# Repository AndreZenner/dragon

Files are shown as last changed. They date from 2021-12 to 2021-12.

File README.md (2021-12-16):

# Drag:on

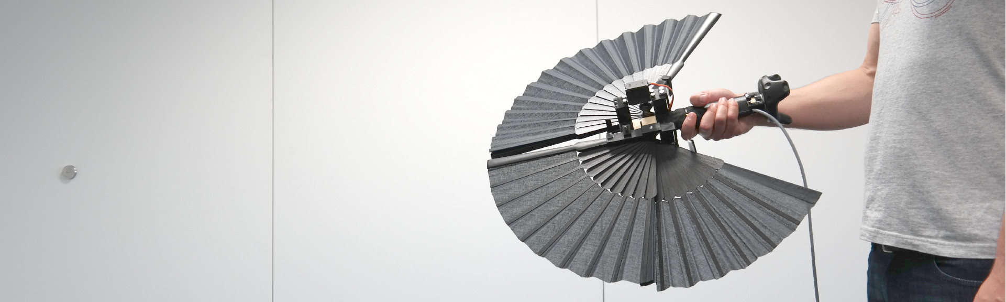
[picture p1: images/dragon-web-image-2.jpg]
Picture of the Drag:on The Drag:on


An assembly kit to build a **Drag:on virtual reality controller with haptic feedback based on air resistance**.  
Below you will find useful links and general instructions, as well as the necessary files, code, and documents.  

Please refer to this repository if you want to re-build Drag:on for private use.
Commercial use of Drag:on and its underlying feedback concept is protected by the following [patent](https://register.dpma.de/DPMAregister/pat/PatSchrifteneinsicht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):

```
Zenner, A. and Krüger, A. (2021). Hand-Virtual Reality/Augmented Reality-Steuergerät, VirtualReality/Augmented Reality-System mit demselben sowie Verfahren zur Simulation der Haptik.
German Patent 10 2019 105 854. June 05, 2021.
Link: https://register.dpma.de/DPMAregister/pat/PatSchrifteneinsicht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
```

## Paper & Video
The original prototype by [André Zenner (DFKI, Germany)](https://umtl.cs.uni-saarland.de/people/andre-zenner.html) and [Antonio Krüger (DFKI, Germany)](https://umtl.cs.uni-saarland.de/people/prof.-dr.-antonio-kr%C3%BCger.html) is described in detail in the corresponding research article.  
Here you can find the [paper](https://umtl.cs.uni-saarland.de/paper_preprints/zenner-krueger-dragon-chi-19-pre-print.pdf) and [video](https://youtu.be/Wf1Ls4M2afg).

### Reference
Please cite the research article using the reference information below:
```
André Zenner and Antonio Krüger. 2019. 
Drag:on - A Virtual Reality Controller Providing Haptic Feedback Based on Drag and Weight Shift. 
In Proceedings of the 2019 CHI Conference on Human Factors in Computing Systems (CHI ’19). 
Association for Computing Machinery, New York, NY, USA, Paper 211, 1–12. 
DOI: https://doi.org/10.1145/3290605.3300441
```

### BibTeX
If using BibTeX, please use the entry below:
```
@inproceedings{Zenner:2019:Dragon,
author = {Zenner, Andr\'{e} and Kr\"{u}ger, Antonio},
title = {Drag:on -- A Virtual Reality Controller Providing Haptic Feedback Based on Drag and Weight Shift},
year = {2019},
isbn = {9781450359702},
publisher = {Association for Computing Machinery},
address = {New York, NY, USA},
url = {https://doi.org/10.1145/3290605.3300441},
doi = {10.1145/3290605.3300441},
booktitle = {Proceedings of the 2019 CHI Conference on Human Factors in Computing Systems},
pages = {1–12},
numpages = {12},
keywords = {haptic virtual reality controller, shape-changing devices, air resistance feedback, dynamic passive haptic feedback},
location = {Glasgow, Scotland Uk},
series = {CHI ’19}
}
```

## What You Will Need
Apart from the ability to solder basic components and basic DIY skills, you will need access to:
*  soldering equipment
*  a workbench
*  a 3D printer
*  a laser cutter (optional)

## Required Parts
To build a Drag:on, you will need the basic physical parts listed below:

| Amount | Part | Comment |
| --- | --- | --- |
| 1 | 7.5V Power Supply | [Example](https://www.amazon.de/s?k=Universal+Netzteil&__mk_de_DE=%C3%85M%C3%85%C5%BD%C3%95%C3%91&ref=nb_sb_noss_2) |
| > 10m | Cable (8 poles, shielded) | [Example](https://www.reichelt.de/steuerleitung-8x0-14mm-geschirmt-50m-ring-liycy-08-50-p10314.html?&trstct=pos_0&nbc=1) |
| 1 | Plug (8 poles) | must match socket |
| 1 | Socket (8 poles) | [Example](https://www.reichelt.de/mikrofon-kupplung-f-funkgeraete-8-polig-m-608-p11166.html?&trstct=pos_0&nbc=1) |
| 2 | MG996R servo motor with metal gears | [Example](https://www.amazon.de/dp/B07H89JH74/ref=pe_3044161_185740101_TE_item) |
| 1 | Power supply socket | [Example](https://www.ebay.de/itm/5x-Stromversorgungsbuchse-fur-Arduino-5-5-2-1mm-DC022B-Hohlstecker-Einbau/182920397905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) |
| 1 | 1/4 inch screw (camera screw; 12mm x 14mm) | [Example](https://www.amazon.de/dp/B0725VQ2N3/ref=pe_3044161_185740101_TE_item) |
| 1 pack | tesa Powerstrips Large | [Example](https://www.amazon.de/dp/B000KJOC78/ref=pe_3044161_185740101_TE_item) |
| 1 | Arduino Nano | [Example](https://store.arduino.cc/arduino-nano) |
| 1 | Button | [Example](https://www.amazon.de/dp/B07DF5NTZN/ref=pe_3044161_185740101_TE_item) |
| 1 | Vive Tracker | [Example](https://www.vive.com/de/vive-tracker/) |
| 2 | Fans (31 cm) | [Example](https://www.flamenco-kleider.de/product_info.php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) |
| | 3D printed parts | see [3d-printer](3d-printer) |
| 1 | Drag:on PCB (or Breadboard) | see [circuit](circuit) |
| | basic electronic parts (resistors, capacitors, etc.) | see [circuit](circuit) |
| (1) | box to hold the electronics | see [laser-cutter](laser-cutter) |

## Required Files
Apart from the physical parts, you will need a set of files.  
All these files can be found in this Git repository:
*  3D models (`*.stl` format) to print in folder [`3d-printer`](3d-printer)
*  laser cutter templates (`*.svg` format) to cut in folder [`laser-cutter`](laser-cutter)
*  circuit description (an image) in folder [`circuit`](circuit)
*  source code for the Arduino Nano (the Drag:on firmware) in folder [`dragon-arduino`](dragon-arduino)
*  source code for Unity (the Drag:on `.unitypackage`) in folder [`dragon-unity`](dragon-unity)

## Main Steps
Follow the steps below to build a Drag:on.

### Preparation
1.  Buy all necessary components (see table above)
2.  3D print all required parts (see [video](https://youtu.be/Wf1Ls4M2afg) for part count and [`3d-printer`](3d-printer) for files)
3.  (Laser cut a nice box to hold the electronics - optional - see [`laser-cutter`](laser-cutter) for files and image below for an example)

### Assembly
1.  Assemble the circuit (see image below and [`circuit`](circuit))
2.  Assemble the actual device using the parts you bought and the 3D-printed components. Refer to the [video](https://youtu.be/Wf1Ls4M2afg) and the images on this site to see how it should look at the end. Also, take a look at the [explosion animation](https://youtu.be/Wf1Ls4M2afg?t=117). If you need close-up pictures of any details or parts, please contact [André Zenner](https://umtl.cs.uni-saarland.de/people/andre-zenner.html) (andre.zenner@dfki.de).
3.  Deploy the Arduino source code on the Nano (see [`dragon-arduino`](dragon-arduino))

Drag:on Rendering 1 | Drag:on Rendering 2 | Drag:on Rendering 3
:-------------------------:|:-------------------------:|:-------------------------:
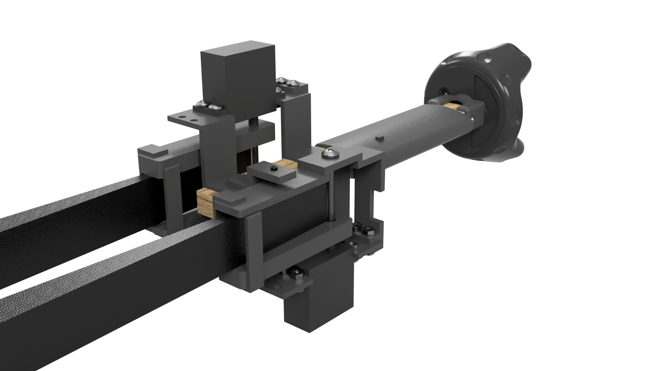
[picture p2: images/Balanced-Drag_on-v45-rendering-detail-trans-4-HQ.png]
Drag:on Rendering 1
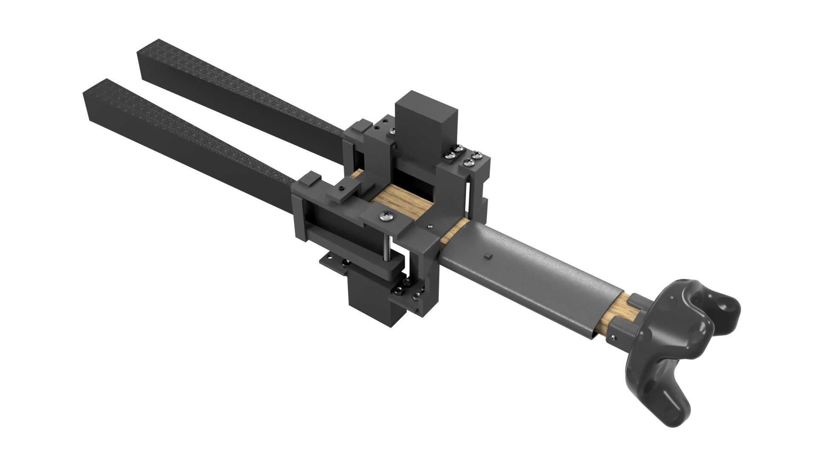
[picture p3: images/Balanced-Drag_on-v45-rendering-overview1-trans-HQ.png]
Drag:on Rendering 2
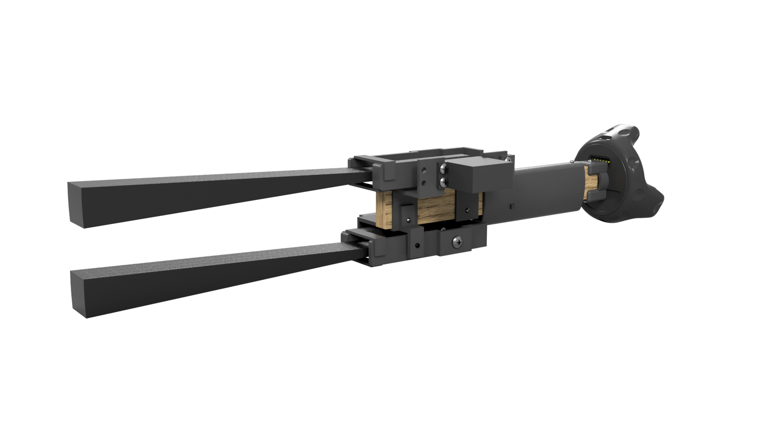
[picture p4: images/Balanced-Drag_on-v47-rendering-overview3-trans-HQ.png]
Drag:on Rendering 3
  |   | 

Drag:on Controller Box | Drag:on Circuit | Final Drag:on
:-------------------------:|:-------------------------:|:-------------------------:
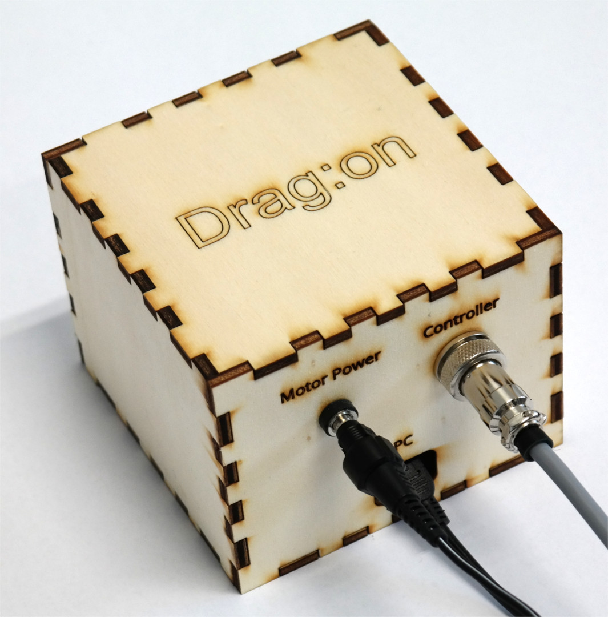
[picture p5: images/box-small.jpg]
Picture of the Drag:on box The Drag:on box.
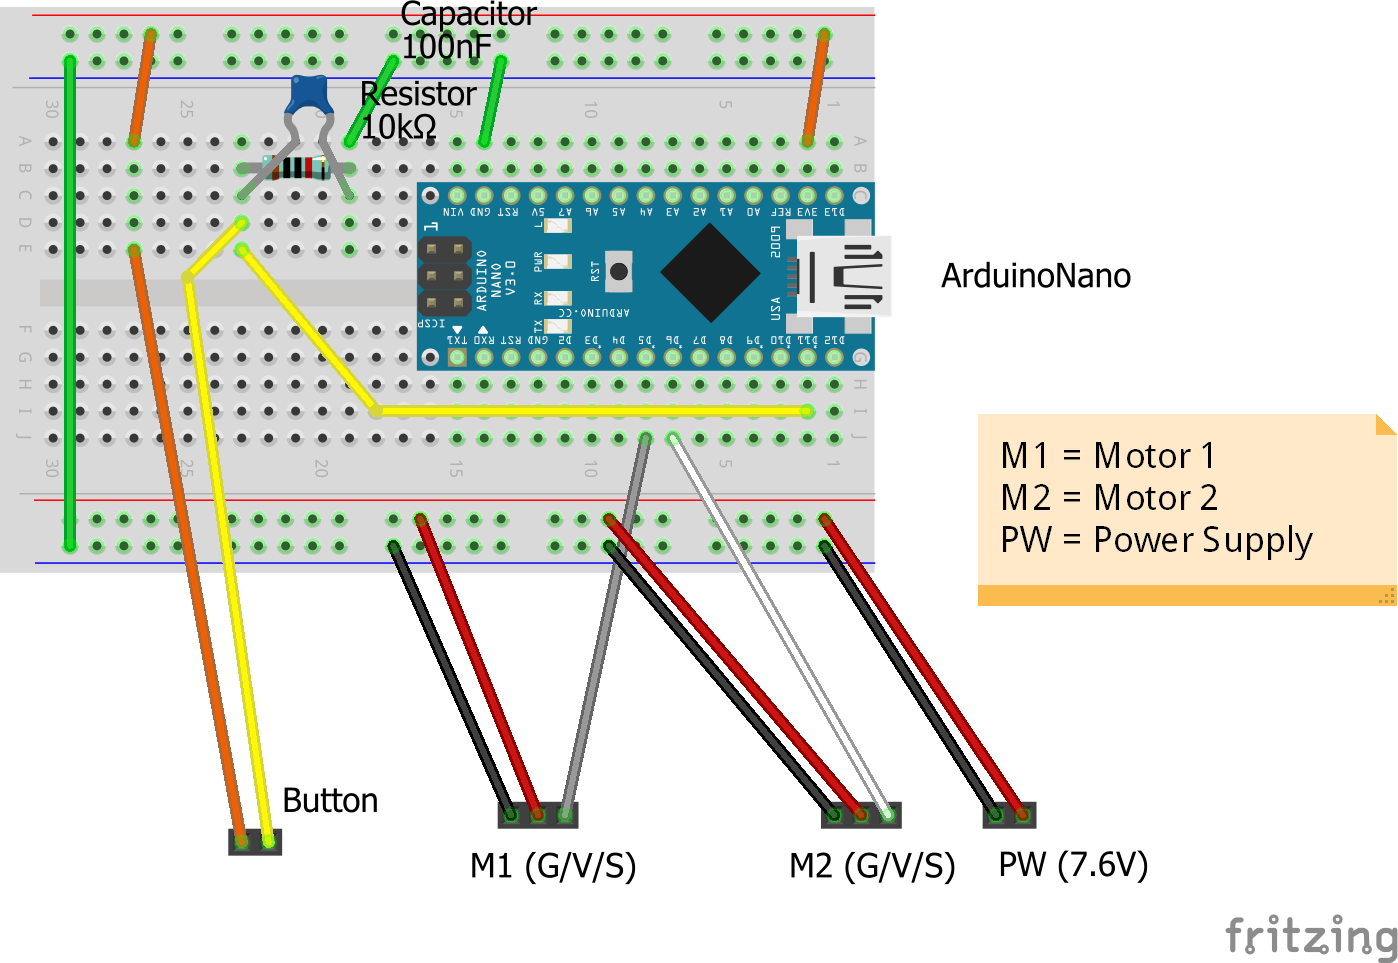
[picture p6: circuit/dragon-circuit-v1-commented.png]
Illustration of the Drag:on circuit The Drag:on circuit.
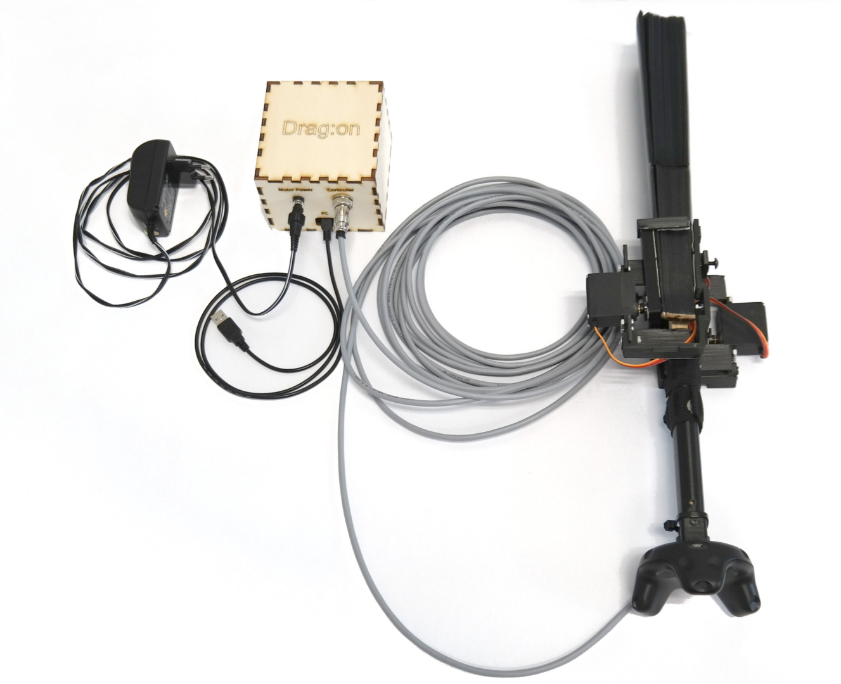
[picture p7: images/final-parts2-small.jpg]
Picture of the final assembly The assembled parts of the Drag:on.
 |   | 

### Standalone Test
1.  Connect everything
2.  Test the device itself (standalone mode). For this, start the device by powering it up while holding the button pressed. Now each button press should change the state of the Drag:on and move its two fans.

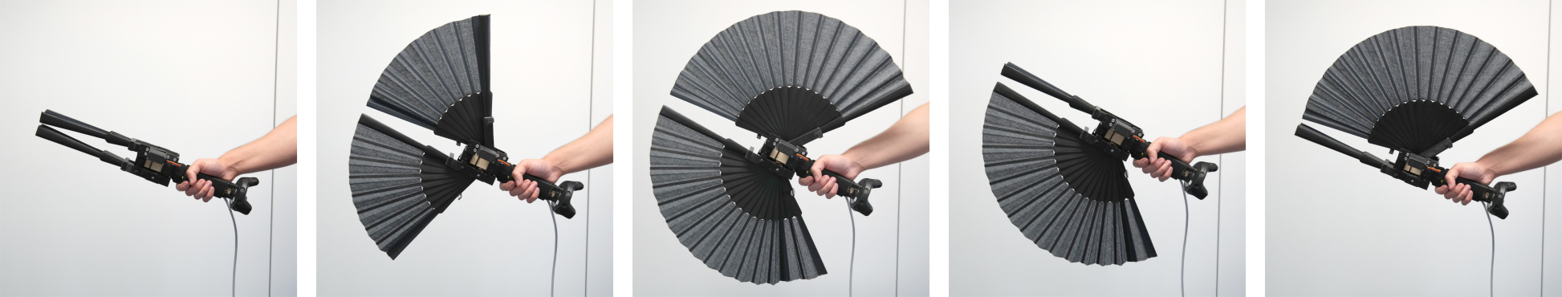
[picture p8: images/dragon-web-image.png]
Picture of the Drag:on states The Drag:on states.


### Unity Integration
1.  If the standalone test was successful, turn to the Unity Package provided in [`dragon-unity`](dragon-unity).
    1.  Import the package into a new Unity project.
    2.  To use the COM port connection to the Drag:on device, you have to switch to `.NET 4.x` support. For this, go to `Edit -> Project Settings -> Player` and select as `Api Compatibility Level` `.NET 4.x` (instead of `.NET Standard 2.0`; see screenshots below).
    3.  When the initial errors are fixed, have a look at the example scene that integrates the device.
        1.  The scene contains a prefab `Drag:on` that holds a simple 3D model of the device, text indicators to display the current device transformation progress, and most importantly, the `Dragon.cs` and `DragonTest.cs` C# scripts.
        2.  The `Dragon` script implements the interface to send commands to the Drag:on device and read out its internal state. Be sure to **select the correct COM port in the Unity Editor** (see left image below).
        3.  The `DragonTest` script allows to easily trigger the important functions for test purposes via the keyboard. Just hover over "Dragon" to see a tooltip. You can select the desired target fan positions using the sliders `Percent A` and `Percent B` and then press `2` on the keyboard to transform Drag:on into this state (see right image below).
        4.  Please see the comments in the code for additional information.
2.  To integrate the device into a VR application, use a Vive Tracker and the [SteamVR Plugin](https://assetstore.unity.com/packages/tools/integration/steamvr-plugin-32647).
    1.  Screw the Vive Tracker to the Tracker Module at the end of the device grip.
    2.  Calibrate the tracking in the scene so that the real and virtual Drag:on are aligned.

Initial Errors | Select `Project Settings` | Switch `API Compaltibility Level`
:-------------------------:|:-------------------------:|:-------------------------:
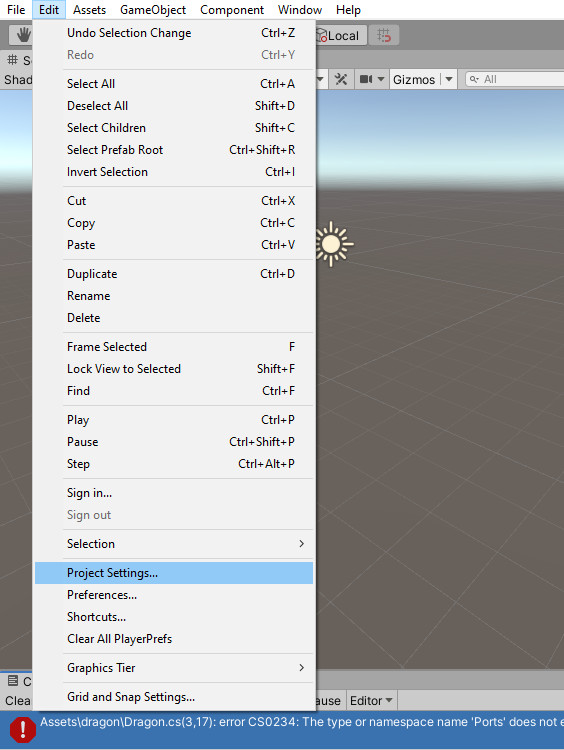
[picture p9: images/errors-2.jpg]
Select Project Settings Select Project Settings.
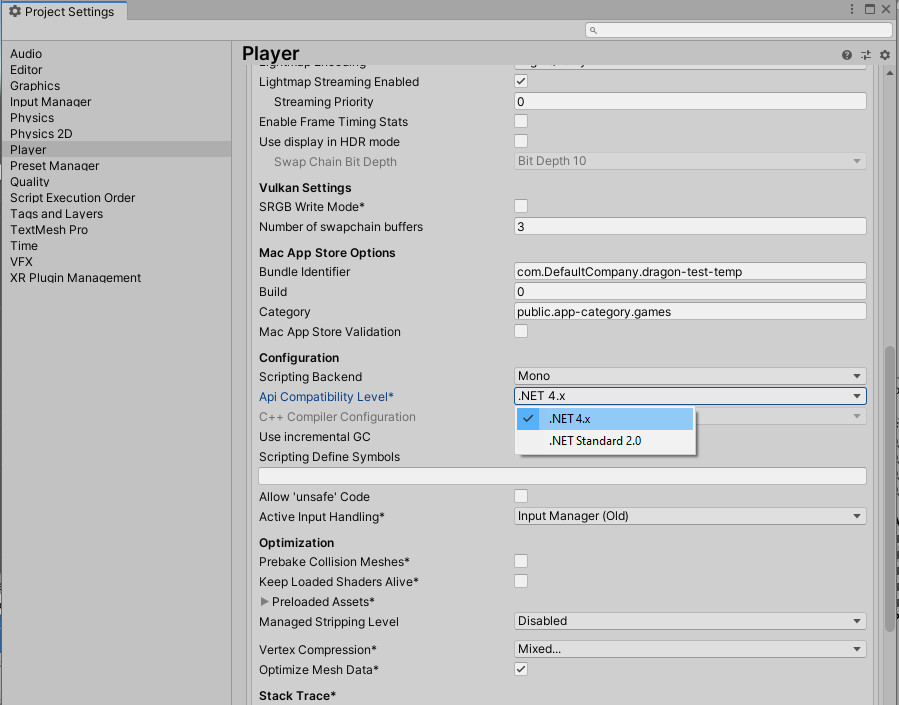
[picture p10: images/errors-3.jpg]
Switch API Compaltibility Level Switch API Compaltibility Level.
The expected initial errors The expected initial errors. |   | 

`Dragon.cs` script | `DragonTest.cs` script
:-------------------------:|:-------------------------:
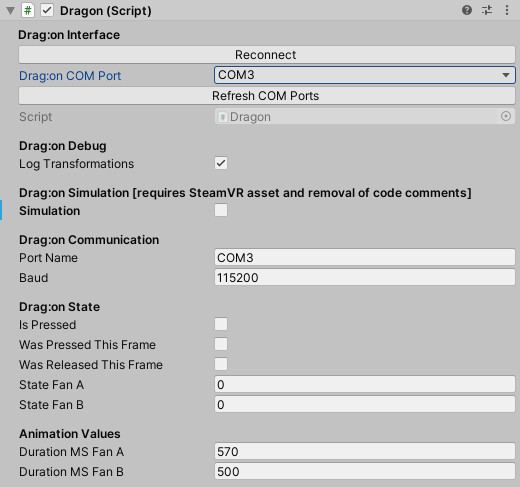
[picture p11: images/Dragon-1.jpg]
Screenshot of the Dragon.cs script Unity Editor interface The Dragon.cs script Unity Editor interface.
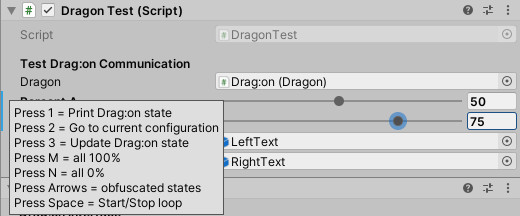
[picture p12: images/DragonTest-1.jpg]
Screenshot of the DragonTest.cs script Unity Editor interface The DragonTest.cs script Unity Editor interface.
 | 

## Contact
For any questions contact [André Zenner](https://umtl.cs.uni-saarland.de/people/andre-zenner.html) (andre.zenner@dfki.de).

## Attribution
When you use a Drag:on in your project, please acknowledge the original [paper](https://umtl.cs.uni-saarland.de/paper_preprints/zenner-krueger-dragon-chi-19-pre-print.pdf) and the resources provided by the authors to build the device in your official documents, published papers, videos, or websites (by citing the paper using the reference above and acknowledging the support).  
**Please also inform [André Zenner](https://umtl.cs.uni-saarland.de/people/andre-zenner.html) (andre.zenner@dfki.de) about your project - we love to hear about it and see what you'll use the Drag:on for!**

This work was supported by the [Deutsches Forschungszentrum für Künstliche Intelligenz GmbH](https://www.dfki.de/) (DFKI; German Research Center for Artificial Intelligence) and [Saarland University](https://www.uni-saarland.de/).
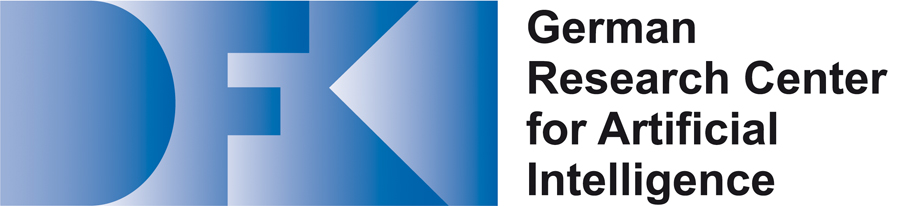
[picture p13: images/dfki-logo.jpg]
DFKI Logo

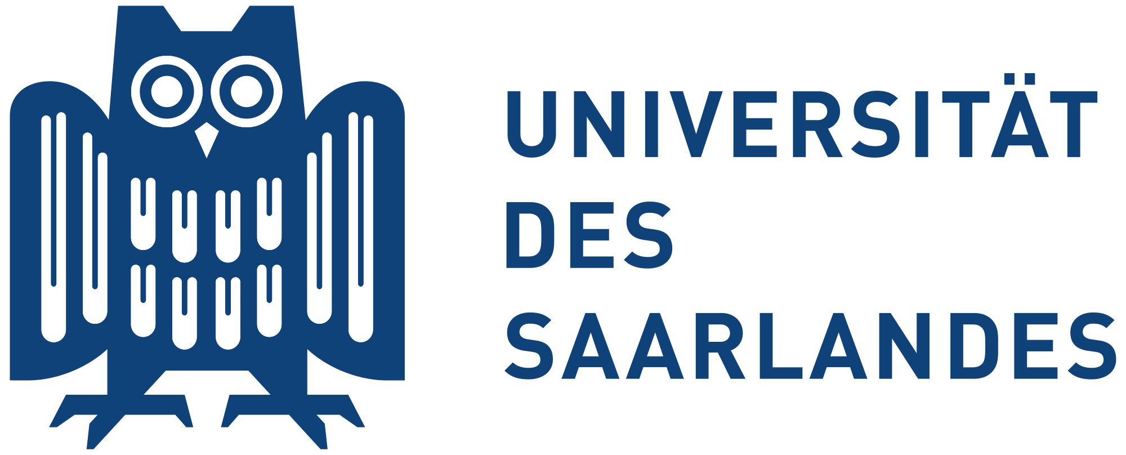
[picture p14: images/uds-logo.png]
Saarland University Logo


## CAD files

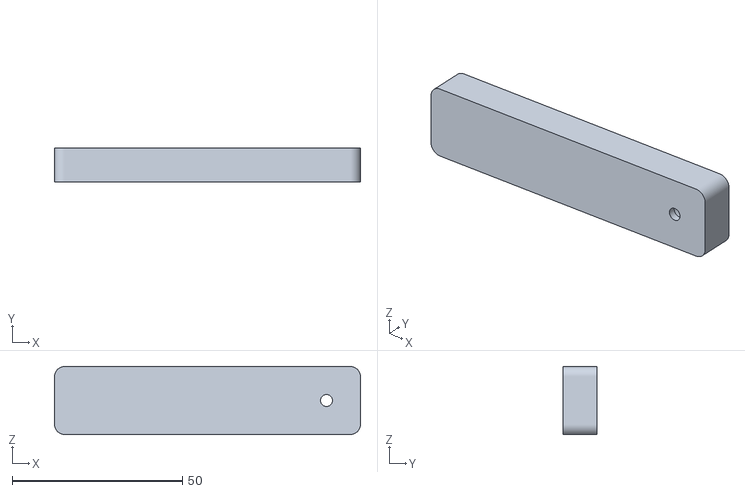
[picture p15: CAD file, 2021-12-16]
3d-printer/dragon-fan-lever-2-v2.stl
90.0 x 10.0 x 20.0

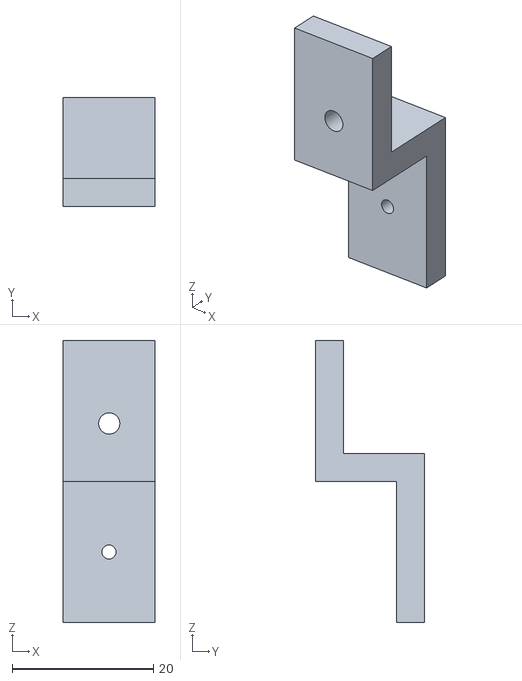
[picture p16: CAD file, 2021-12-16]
3d-printer/dragon-bridge-clip-v3.stl
13.0 x 15.5 x 40.0

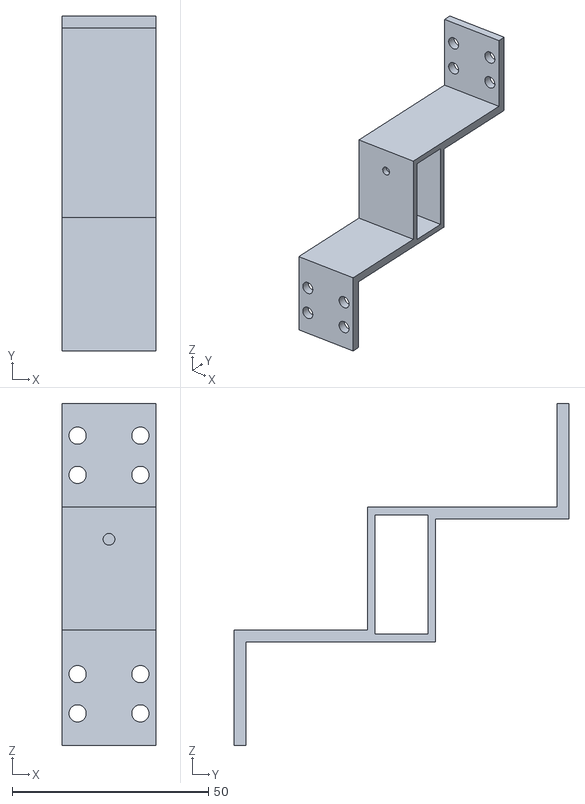
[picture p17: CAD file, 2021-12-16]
3d-printer/dragon-motor-module-v6.stl
24.0 x 85.4 x 87.2

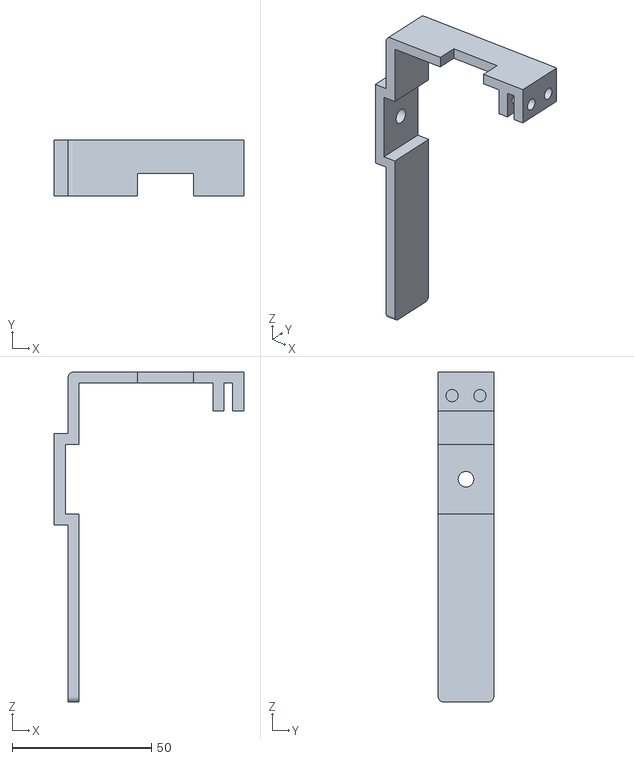
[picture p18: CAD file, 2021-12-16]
3d-printer/dragon-bridge-v7.stl
68.1 x 20.0 x 118.5

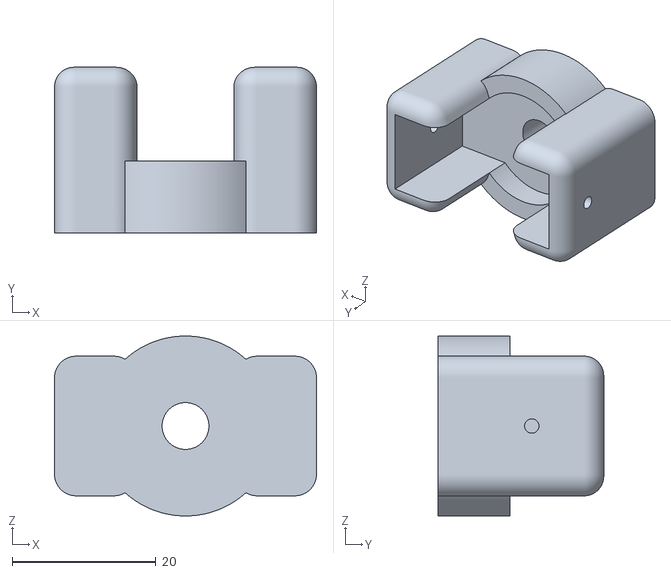
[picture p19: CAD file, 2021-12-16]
3d-printer/dragon-tracker-module-v11.stl
36.4 x 23.0 x 25.0

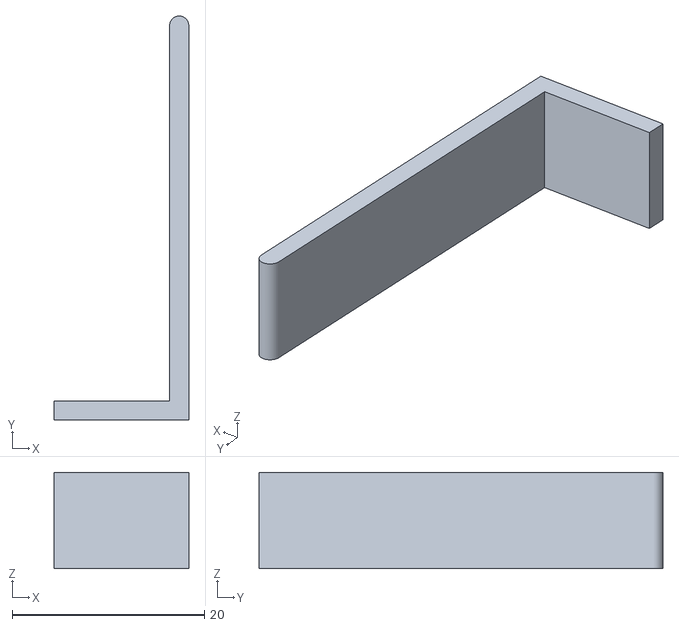
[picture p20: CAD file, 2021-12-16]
3d-printer/dragon-support-arm-to-collect-fan-v6.stl
14.0 x 42.0 x 10.0

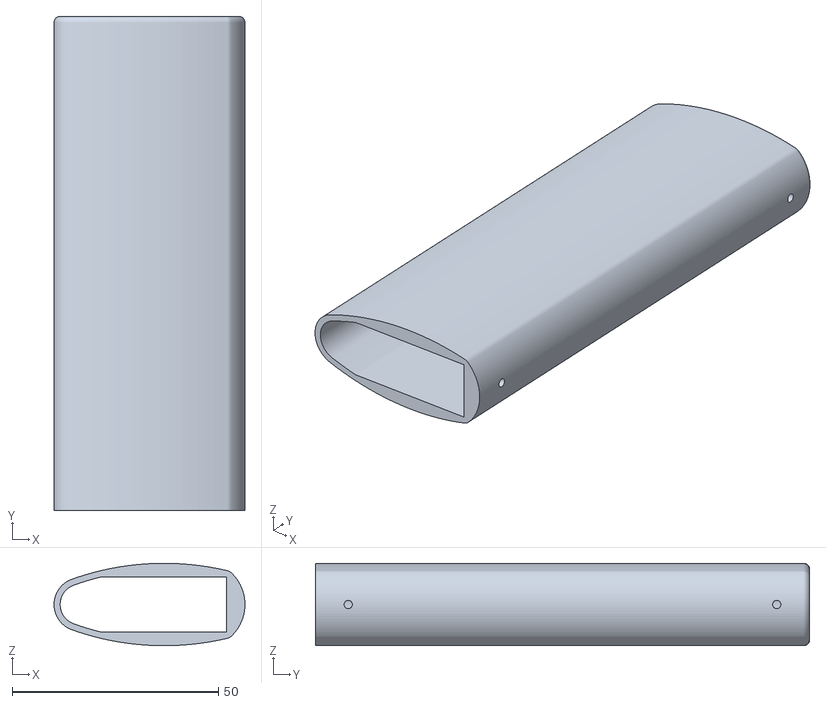
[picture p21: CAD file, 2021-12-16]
3d-printer/dragon-grip-module-v13-10mm.stl
46.4 x 120.0 x 20.0

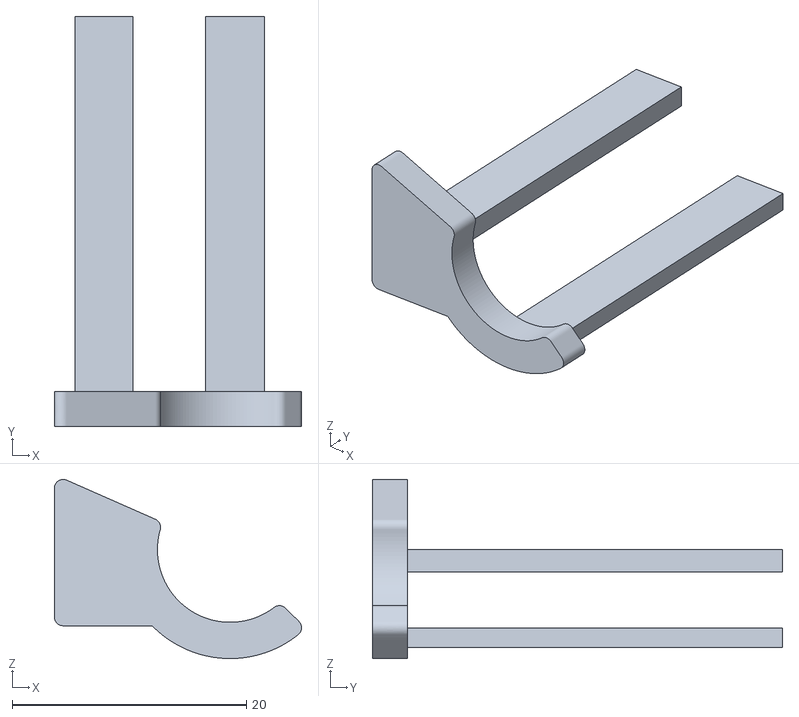
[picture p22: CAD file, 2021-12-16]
3d-printer/dragon-tracker-module-inset-holding-camera-screw-v11.stl
21.1 x 35.0 x 15.3

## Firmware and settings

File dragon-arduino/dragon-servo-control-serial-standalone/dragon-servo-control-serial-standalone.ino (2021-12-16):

/*
 * Serial - Drag:on Servo Control Software [normal & standalone]
 * 
 * Author: André Zenner
 * Date: January 2020
 * 
 * Libraries used:
 *    * ArduinoSerialCommand by Steven Cogswell - GNU LGPL 2.1 (https://github.com/scogswell/ArduinoSerialCommand)
 *    [* esp8266/Arduino - GNU LGPL 2.1 (https://github.com/esp8266/Arduino)] - only if using ESP8266 (Wemos)
 *    [* espsoftwareserial - (https://github.com/plerup/espsoftwareserial)] - only if using ESP8266 (Wemos)
 * 
 * LISTENS FOR COMMANDS VIA SERIAL
 * SEND ASCII TO THIS UNIT. Example:
 * "FANS 30 100"  --> Opens FAN A 30% and FAN B 100%
 * "FANS X 40"    --> Opens FAN B 40% and leaves FAN A as is
 * "STATE"        --> Returns current relative position of fans (in percent) (FAN-A 30 FAN-B 100)
 * 
 * SENDS ASCII WHEN BUTTON PRESSED/RELEASED
 * "BUTTON PRESSED"
 * "BUTTON RELEASED"
 * 
 * BALANCED VERSION - FAN B LIMITED DUE TO HAND/ARM RESTRICTIONS
 * 
 * COMBINED NORMAL & STANDALONE VERSION:
 *    --> TO START IN STANDALONE MODE: KEEP BUTTON PRESSED WHEN BOOTING ARDUINO --> GREEN LIGHT FLASHING 10X
 *    --> TO START IN NORMAL MODE: DO NOT PRESS BUTTON WHEN BOOTING
 * */

//include libs
#include <SoftwareSerial.h>
#include <SerialCommand.h>
#include <Servo.h>

//definations
#define VERSION 13           //the current version
#define SERVO_PIN_1 5      //labeled D5, see https://wiki.wemos.cc/products:d1:d1_mini#technical_specs
#define SERVO_PIN_2 6      //labeled D6
#define BUTTON_PIN 11       //labeled D11
#define BUILTIN_LED 13      //nano LED at 13

//servo parameters
Servo servoA;  // create servo object to control a servo
Servo servoB;
int degMax = 125;    //ATTENTION: 130 deg == FAN OPEN -- 0 deg = FAN CLOSED
int degMin = 0;
float limitationB = 0.86f;
int posA, posB;    // variable to store the servo position

//button
bool curPressed = false;

//serial communication
SerialCommand scmd;

//STANDALONE MODE
bool isStandalone = false;
int currentStateIndex = 0;
int numberStates = 5;
bool switchState = false;

void setup()
{
  //prepare pins
  Serial.begin(115200);
  while(!Serial);
  randomSeed(analogRead(1));      //random init
  pinMode(BUILTIN_LED, OUTPUT);   //status LED on chip
  pinMode(BUTTON_PIN, INPUT);
  servoA.attach(SERVO_PIN_1);
  servoB.attach(SERVO_PIN_2); 
  
  //servo at start position
  posA = degMin;
  posB = degMin;
  servoA.write(posA);              // tell servo to go to position in variable 'pos'
  servoB.write(posB);

  //wait for everything to be set up
  delay(2000);

  //output version
  Serial.print("Drag:on-Unit v");
  Serial.print(VERSION);
  Serial.println("-s&n");

  //STANDALONE OR NORMAL MODE
  isStandalone = digitalRead(BUTTON_PIN) == HIGH;

  if(isStandalone){
    //output mode
    Serial.println("STANDALONE MODE ACTIVE");
  
    //indicate initialization finished
    blinkLED(10,300);
  }else{
    //output mode
    Serial.println("NORMAL MODE ACTIVE");
      
    //serial communication protocol
    scmd.addCommand("FANS", fansHandler);
    scmd.addCommand("STATE", stateHandler);
    
    //indicate initialization finished
    blinkLED(1,2000);
  }
}


void loop()
{
  //BUTTON HANDLING
  //check for button state
  if(curPressed && digitalRead(BUTTON_PIN) == LOW){
    Serial.println("BUTTON RELEASED");
    curPressed = false;
    digitalWrite(BUILTIN_LED, LOW);
  }
  if(!curPressed && digitalRead(BUTTON_PIN) == HIGH){
    if(isStandalone){
      switchState = true;
    }
    Serial.println("BUTTON PRESSED");
    curPressed = true;
    digitalWrite(BUILTIN_LED, HIGH);
  }

  //NORMAL MODE: check for new commands
  if (!isStandalone && Serial.available() > 0)
    scmd.readSerial();

  //STANDALONE MODE: switch to next state
  if(isStandalone && switchState){
    switchState = false;
    currentStateIndex = (currentStateIndex + 1) % numberStates;
    if(currentStateIndex == 0){
      fansHandlerSTR("0", "0");
    } else if(currentStateIndex == 1){
      fansHandlerSTR("100", "100");
    } else if(currentStateIndex == 2){
      fansHandlerSTR("100", "0");
    } else if(currentStateIndex == 3){
      fansHandlerSTR("50", "50");
    } else if(currentStateIndex == 4){
      fansHandlerSTR("0", "100");
    } 
  }
}

//transform fans from serial command
void fansHandler () {
  const char *argA = scmd.next();
  const char *argB = scmd.next();
  fansHandlerSTR(argA, argB);
}

//transform fans from string
void fansHandlerSTR(const char *percentA, const char *percentB){
  const char *arg;
  int targetA = posA;
  int targetB = posB;
  
  //read target A
  arg = percentA;
  if(arg != NULL){
    if((strcmp(arg, "X") != 0) && (strcmp(arg, "x") != 0)){    //do nothing if "X", else parse target position
      targetA = (int)((atof(arg) / 100.0) * (degMax - degMin)) + degMin;
      if(degMin > targetA || targetA > degMax){
        targetA = posA;
      }
    }
  }

  //read target B 
  arg = percentB;
  if(arg != NULL){
    if((strcmp(arg, "X") != 0) && (strcmp(arg, "x") != 0)){    //do nothing if "X", else parse target position
      targetB = (int)((atof(arg) / 100.0) * (degMax - degMin) * limitationB) + degMin;
      if(degMin > targetB || targetB > degMax){
        targetB = posB;
      }
    }
  }

  //apply
  if(targetA != posA){
    posA = targetA;
    servoA.write(posA);
  }
  if(targetB != posB){
    posB = targetB;
    servoB.write(posB);
  }

  //send feedback
  stateHandler();
}

//send current positions of fan
void stateHandler(){
    int percentA = (int)((((float)posA - (float)degMin)/(float)(degMax - degMin))*100.0);
    int percentB = (int)((((float)posB - (float)degMin)/((float)(degMax - degMin) * limitationB))*100.0);
    Serial.print("FAN-A ");
    Serial.print(percentA);
    Serial.print(" FAN-B ");
    Serial.println(percentB);
}

//blink the LED
void blinkLED(int times, int duration){
  for(int i=0; i<times; i++){
    digitalWrite(BUILTIN_LED, HIGH);
    delay(duration);
    digitalWrite(BUILTIN_LED, LOW);
    delay(duration);
  }
}
